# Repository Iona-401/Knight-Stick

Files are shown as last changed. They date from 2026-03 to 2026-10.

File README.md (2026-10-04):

# Knight-Stick 🕹️✈️

An open-source, fully 3D-printable flight stick engineered for high-precision simulation, modular assembly, and custom hardware integration.

---

## Overview

Commercial flight simulation gear is often prohibitively expensive or locked into closed ecosystems. **Knight-Stick** bridges that gap by providing a fully customizable, high-performance flight controller that you can manufacture at home using 3D printing and custom electronics.

Designed with a heavy focus on ergonomic feel, mechanical durability, and low-latency input processing, this project brings together mechanical CAD, PCB design, and embedded firmware.

---

## Key Features

* **Ergonomic & Modular CAD:** Designed for additive manufacturing, optimizing print orientation for strength and tactile comfort.
* **Precision Inputs:** Built around low-latency sensor architecture to ensure smooth, dead-zone-free axis tracking and crisp button actuation.
* **Custom Electronics:** Dedicated PCB layout for clean signal routing and reliable peripheral connections.
* **Open Source:** Complete hardware schematics, firmware source code, and STL/CAD files available for modification and community contribution.

---

## Repository Structure

```text
Knight-Stick/
├── cad/          # 3D printable models, mechanical assemblies, and STEP/STL files
├── hardware/     # Schematics, board layouts, and manufacturing files
├── firmware/     # Microcontroller source code and USB HID implementation
└── docs/         # Build guides, wiring diagrams, and assembly instructions

```

---

## Getting Started & Bill of Materials (BOM)

To build your own Knight-Stick, check out the documentation and release files in the respective directories:

1. **Hardware & Electronics:** Review the `hardware/` folder for schematic diagrams and PCB fabrication files.
2. **Mechanical Parts:** Grab the latest printable parts from the `cad/` folder. Ensure you follow recommended print settings for structural rigidity (e.g., adequate infill and wall counts).
3. **Firmware:** Flash the controller using the source code provided in the `firmware/` directory.

---

## Contributing

Contributions, feedback, and forks are always welcome! If you have ideas for improved gimbal geometry, alternative sensor integrations, or firmware enhancements, feel free to open an issue or submit a pull request.

---

## License

This project is open-source. See the repository for license details.

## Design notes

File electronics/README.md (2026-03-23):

# Electronics

This directory contains the complete electronics design for the **Knight Stick**
flight stick, including the schematic, PCB layout, and manufacturing outputs.

The electronics are built around an **ESP32**, providing USB and/or wireless
capabilities suitable for use as a flight simulation controller or general
HID device.

## Contents

- `kicad/`  
  Source design files created with **KiCad**, including:
  - Schematics
  - PCB layout
  - Project configuration files  
  These files represent the authoritative source for the electronics design.

- `gerbers/`  
  Fabrication-ready Gerber and drill files, organized by hardware revision.
  These files can be used directly with PCB manufacturers.

- `bom/`  
  Bill of Materials (BOM) files listing all electronic components required to
  assemble the PCB.

## Manufacturing Notes

- Gerber files are provided for convenience; always refer to the KiCad source
  files if modifications are required.
- Check the BOM and schematic carefully before ordering or assembling boards.

## License

All electronics design files in this directory are licensed under the  
**CERN Open Hardware License v2 – Strongly Reciprocal (CERN-OHL-S)**.

See the root `LICENSE-hardware.txt` file for full license terms.

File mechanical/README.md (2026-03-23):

# Mechanical Design

This directory contains the mechanical design files for the **Knight Stick**
flight stick. All mechanical components are designed to be **3D printable** and
are intended to integrate with the custom electronics.

The mechanical design was created in **Onshape** and exported for distribution
and fabrication.

## Contents

- 3D model exports (e.g., STEP and STL files) for individual parts and assemblies
- Mechanical drawings and documentation (where applicable)
- Visual assets such as renders or reference images

## 3D Printing Notes

- Parts are intended for consumer-grade FDM 3D printers.
- Recommended print settings (material, layer height, infill, orientation)
  should be documented here as the project matures.
- Verify tolerances before final assembly, especially for moving parts.

## 3D print List

### Grip
- Grip - Head.step :                  x1
- Grip - Left.step :                  x1
- Grip - Right.step :                 x1
- Grip - Trigger.step :               x1
- Grip - Paddle.step :                x1
- Grip - JoyStick Hat.step :          x1
- Grip - Dimple Hat.step :            x2
- Grip - Dome Hat.step :              x1
- Grip - Tact Button Cover.step :     x1
- Grip - Face Button Hat.step :       x1
- Grip - Head Button Hat.step :       x1
- Grip - Base Button Hat.step :       x1
- Grip - Face Plate.step :            x1

### X Axis
- X Axis - Grip Roller Cover.step :   x2
- X Axis - Grip Connector.step :      x1
- X Axis - Bearing Plate.step :       x2
- X Axis - Axis Damper.step :         x2
- X Axis - Roller Cover.step :        x2
- X Axis - Roller Plate.step :        x2

### Y Axis
- Y Axis - Bearing Plate.step :       x2
- Y Xxis - Axis Damper.step :         x2
- Y Axis - Side Plate.step :          x2

### Essentials
- Cams.step :                         x4
- FS - Sensor Holder.step :           x2
- FS-Base.step :                      x1
- FS-Box.step :                       x1

### Pre Made Print Profile
Full FS Print Profile.3mf : Load the File into Orca Slicer and it should load my print settings and the correct number of parts

## Source CAD

The authoritative mechanical design is maintained in Onshape.
Exported files in this directory represent fixed versions of the design at the
time of release.

Complete Model can be accessed at: https://cad.onshape.com/documents/ea7ebc91642e5ab2bd650249/w/252ca4d46198baf62f9cc347/e/4112f2ff40760dfaba3afdd9 

## License

All mechanical design files in this directory are licensed under the  
**CERN Open Hardware License v2 – Strongly Reciprocal (CERN-OHL-S)**.

See the root `LICENSE-hardware.txt` file for full license terms.

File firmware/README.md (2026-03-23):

# Firmware

ESP32 firmware for the 3D-printable flight stick.

VERY MUCH WORK IN PROGRESS

## License
All firmware and software source code in this directory
is licensed under the MIT License.

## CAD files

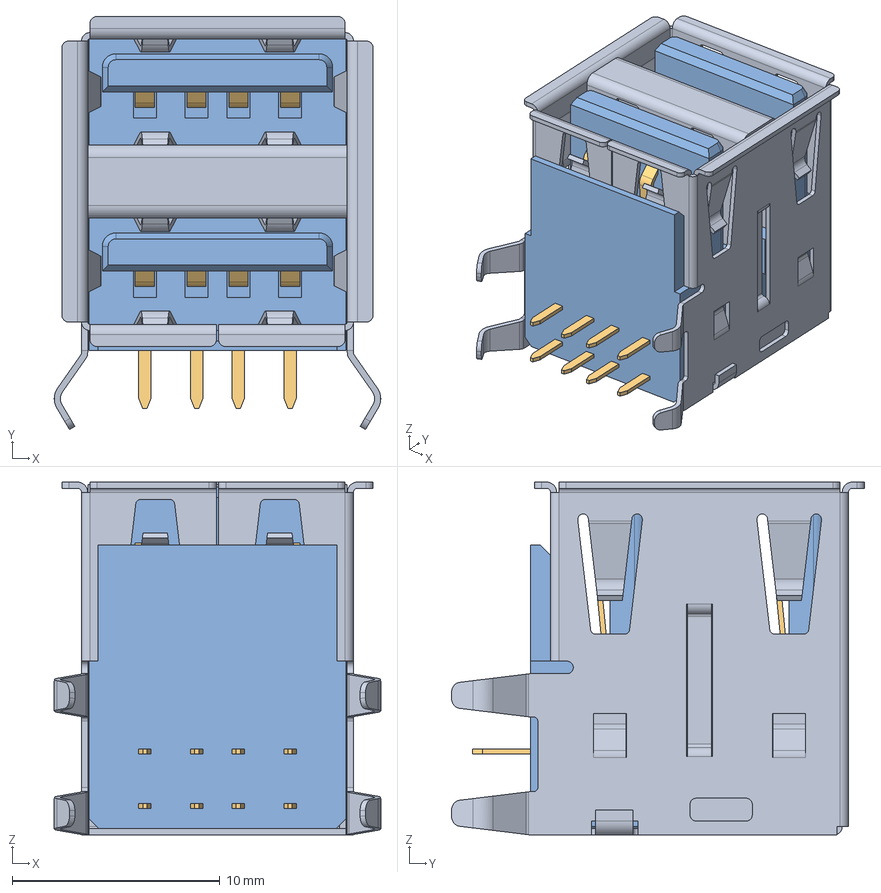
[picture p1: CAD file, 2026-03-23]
electronics/Kicad 3D Models/USB parts - GCT - USB1035-GF-P-0-B-B USB TYPE-A Stacked TH Right Angle.step
15.7 x 19.9 x 17.0 mm

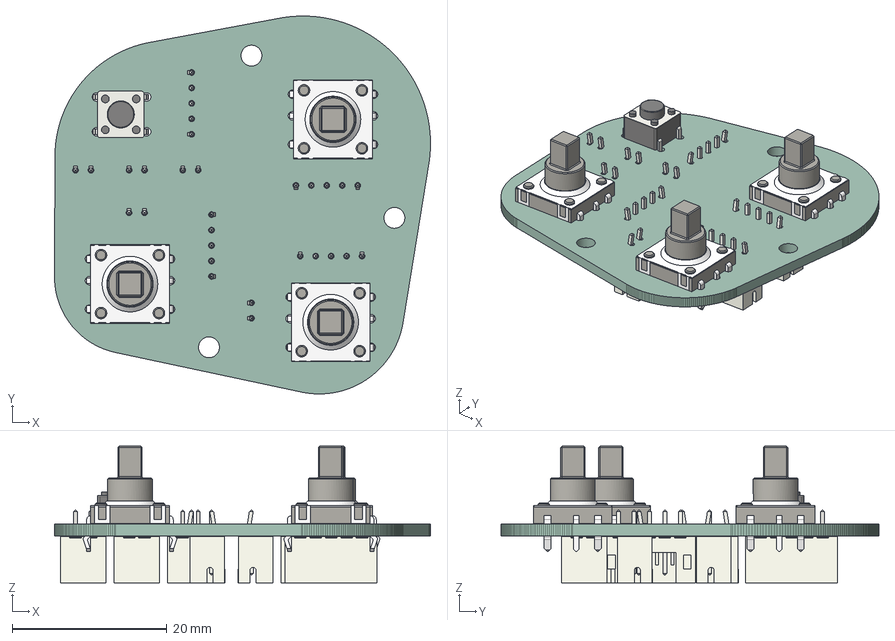
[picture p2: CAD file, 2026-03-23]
electronics/kicad/Faceboard/Faceboard.step
48.7 x 48.9 x 17.7 mm
5Way Pins x 3
5Way Body x 3
5Way Cover x 3
SW_PUSH_6mm_H5mm
JST_PH_B5B-PH-K_1x05_P2.00mm_Vertical x 4
JST_PH_B2B-PH-K_1x02_P2.00mm_Vertical x 5
In-Grip_FacePlate_PCB

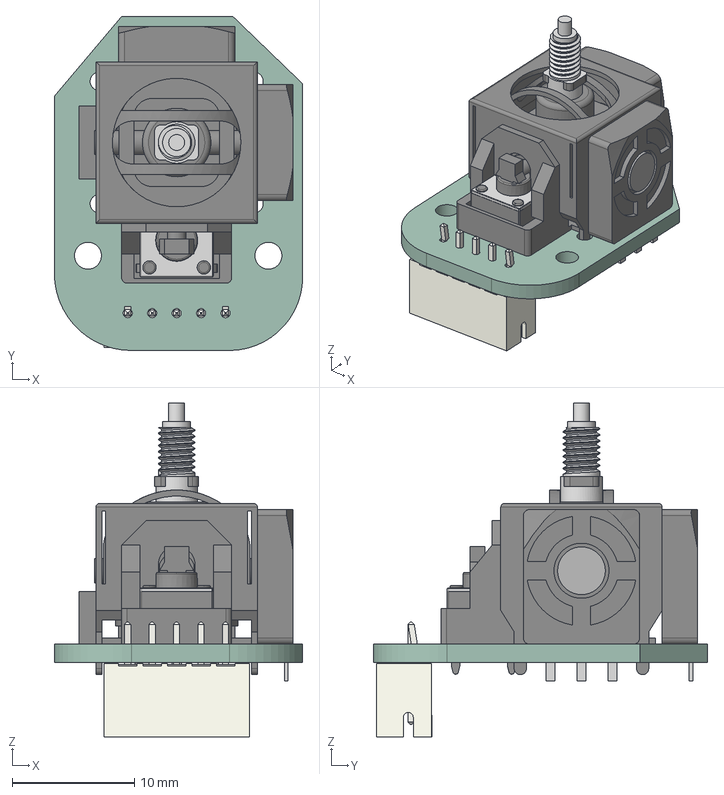
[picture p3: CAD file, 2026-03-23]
electronics/kicad/JoyStick Board/JoyStickBoard.step
20.3 x 27.3 x 27.3 mm
Hall Effect Joystick - Hall Effect Joystick
JST_PH_B5B-PH-K_1x05_P2.00mm_Vertical
JoyStickBoard_PCB

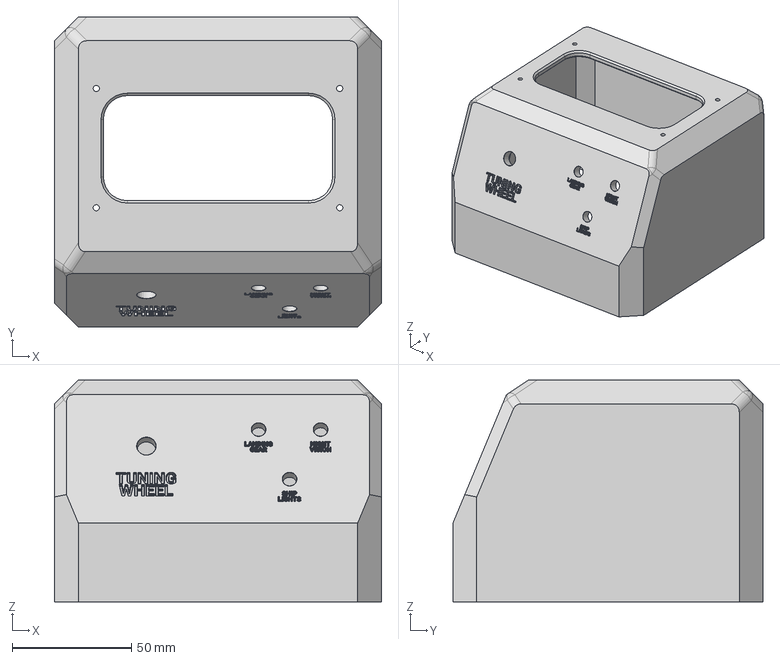
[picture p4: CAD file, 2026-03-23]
mechanical/Essentials/FS-Box.step
137.0 x 130.0 x 93.0 mm

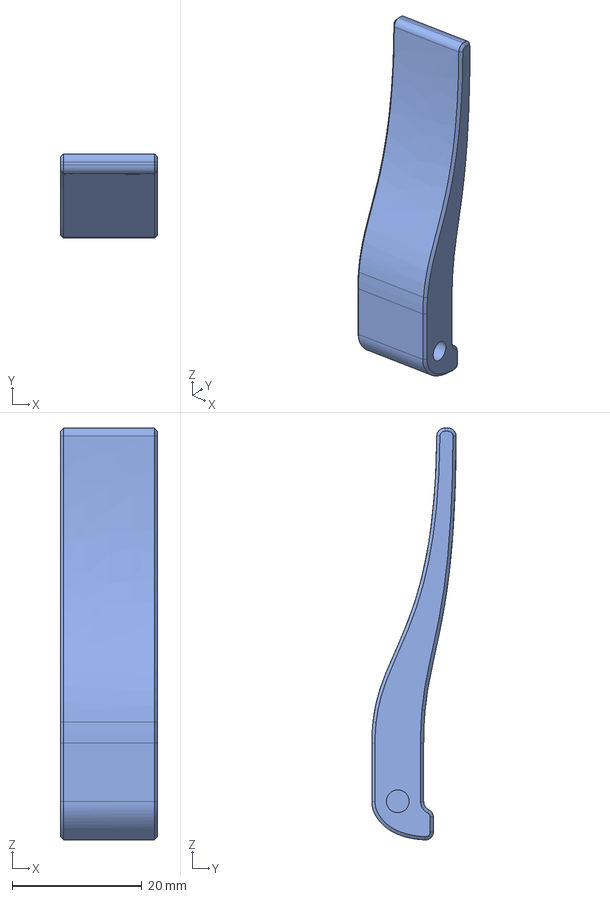
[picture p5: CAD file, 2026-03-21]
mechanical/Grip/Grip - Paddle.step
15.0 x 13.0 x 63.5 mm

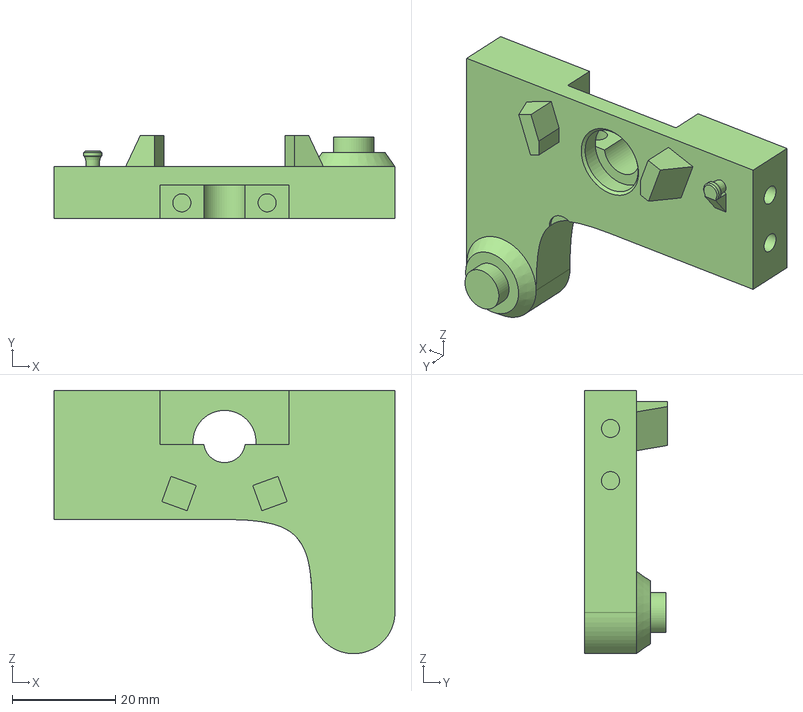
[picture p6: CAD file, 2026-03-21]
mechanical/X Axis/X Axis - Bearing Plate.step
66.0 x 16.0 x 51.0 mm

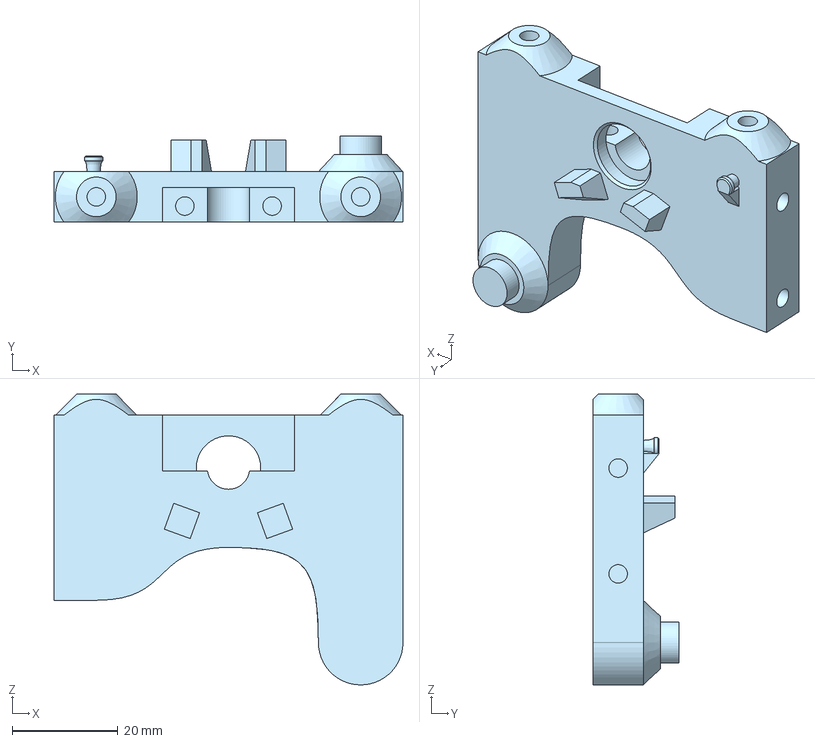
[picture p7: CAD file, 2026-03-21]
mechanical/Y Axis/Y Axis - Bearing Plate.step
66.0 x 16.2 x 55.0 mm

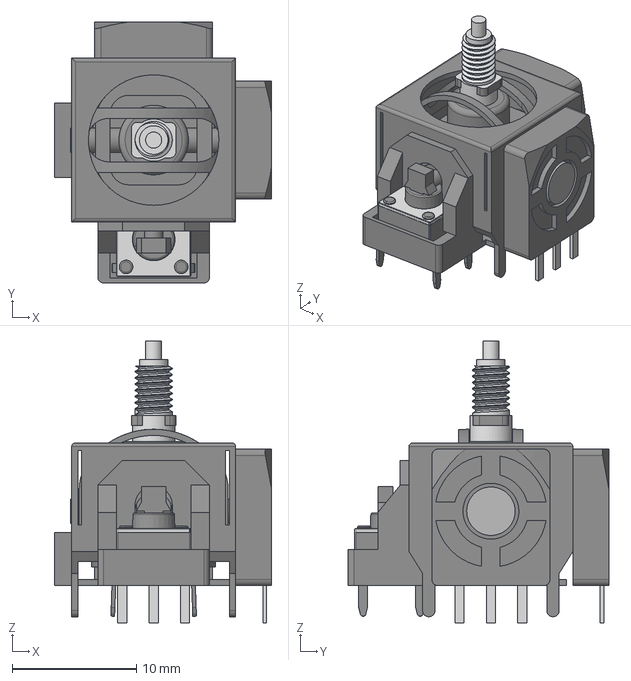
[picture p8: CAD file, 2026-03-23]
electronics/Kicad 3D Models/Hall Effect Joystick - Hall Effect Joystick.step
17.5 x 21.0 x 22.7 mm

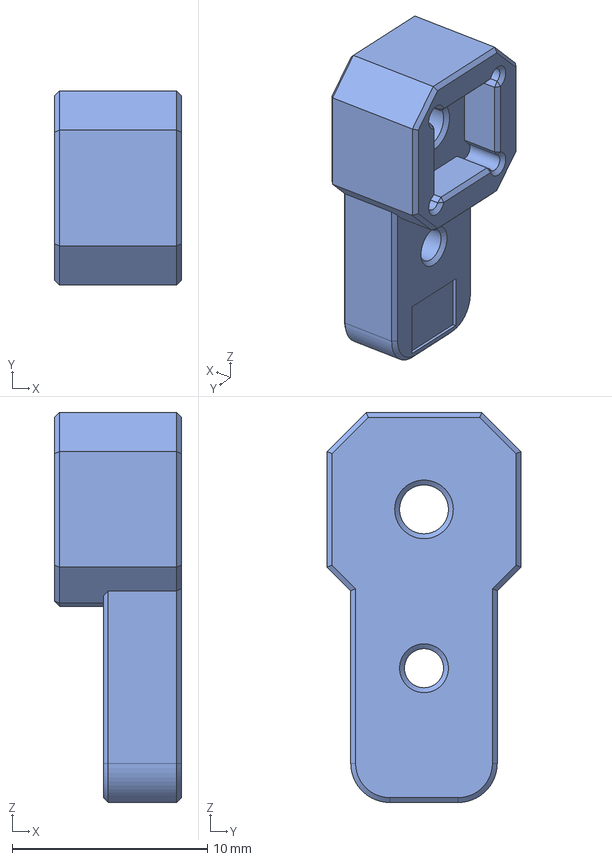
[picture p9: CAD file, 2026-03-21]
mechanical/Essentials/FS - Sensor Holder.step
6.50 x 9.92 x 20.0 mm

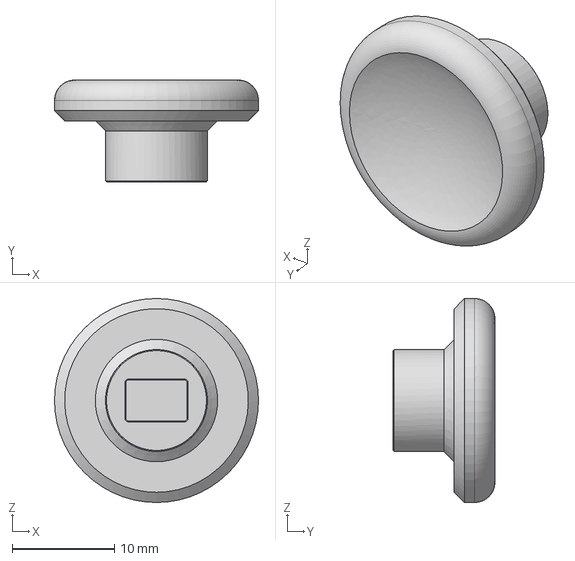
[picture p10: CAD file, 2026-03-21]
mechanical/Grip/Grip - JoyStick Hat.step
20.0 x 10.0 x 20.0 mm

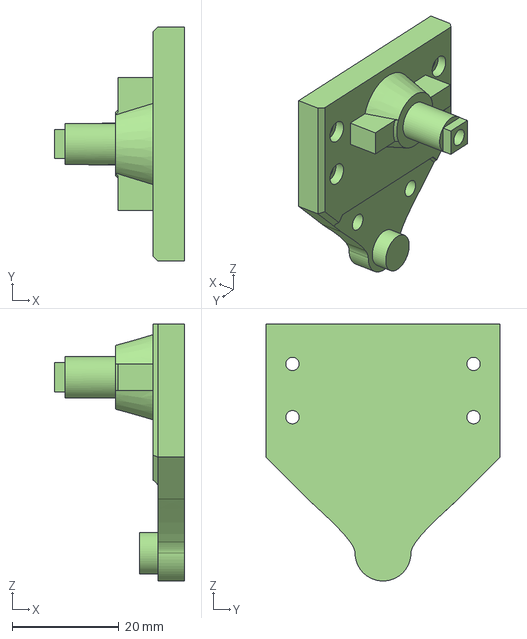
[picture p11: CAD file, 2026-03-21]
mechanical/X Axis/X Axis - Roller Plate.step
24.5 x 44.0 x 48.2 mm

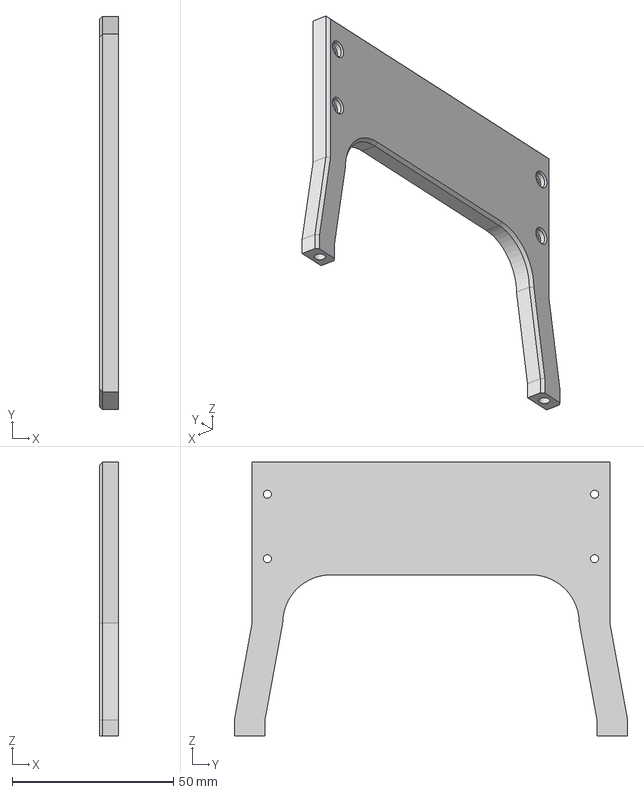
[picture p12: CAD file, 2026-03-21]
mechanical/Y Axis/Y Axis - Side Plate.step
6.00 x 122.0 x 85.0 mm

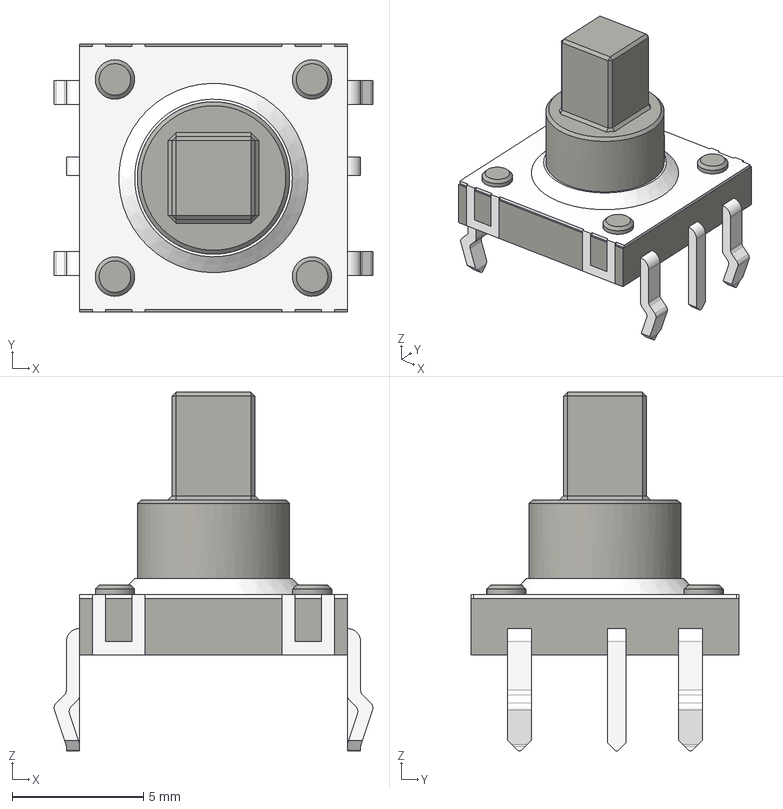
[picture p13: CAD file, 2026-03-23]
electronics/Kicad 3D Models/5-Way Button 10x10x10mm DIP-6.step
12.1 x 10.2 x 13.7 mm

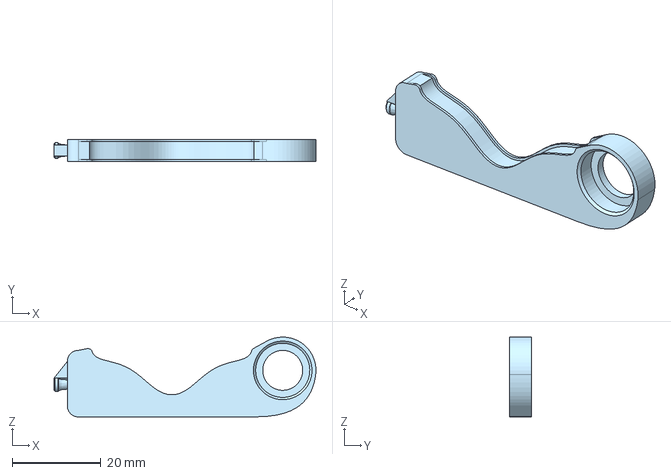
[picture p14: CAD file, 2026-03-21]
mechanical/Essentials/Cams.step
59.0 x 5.00 x 18.0 mm

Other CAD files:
mechanical/Grip/Grip - Right.step
mechanical/X Axis/X Axis - Axis Damper.step
mechanical/Y Axis/Y Xxis - Axis Damper.step
mechanical/Essentials/FS-Base.step
mechanical/Grip/Grip - Base Button Hat.step
mechanical/Grip/Grip - Dimple Hat.step
mechanical/Grip/Grip - Dome Hat.step
mechanical/Grip/Grip - Face Button Hat.step
mechanical/Grip/Grip - Face Plate.step
mechanical/Grip/Grip - Head Button Hat.step
mechanical/Grip/Grip - Head.step
mechanical/Grip/Grip - Left.step
mechanical/Grip/Grip - Tact Button Cover.step
mechanical/Grip/Grip - Trigger.step
mechanical/X Axis/X Axis - Grip Connector.step
mechanical/X Axis/X Axis - Grip Roller Cover.step
mechanical/X Axis/X Axis - Roller Cover.step

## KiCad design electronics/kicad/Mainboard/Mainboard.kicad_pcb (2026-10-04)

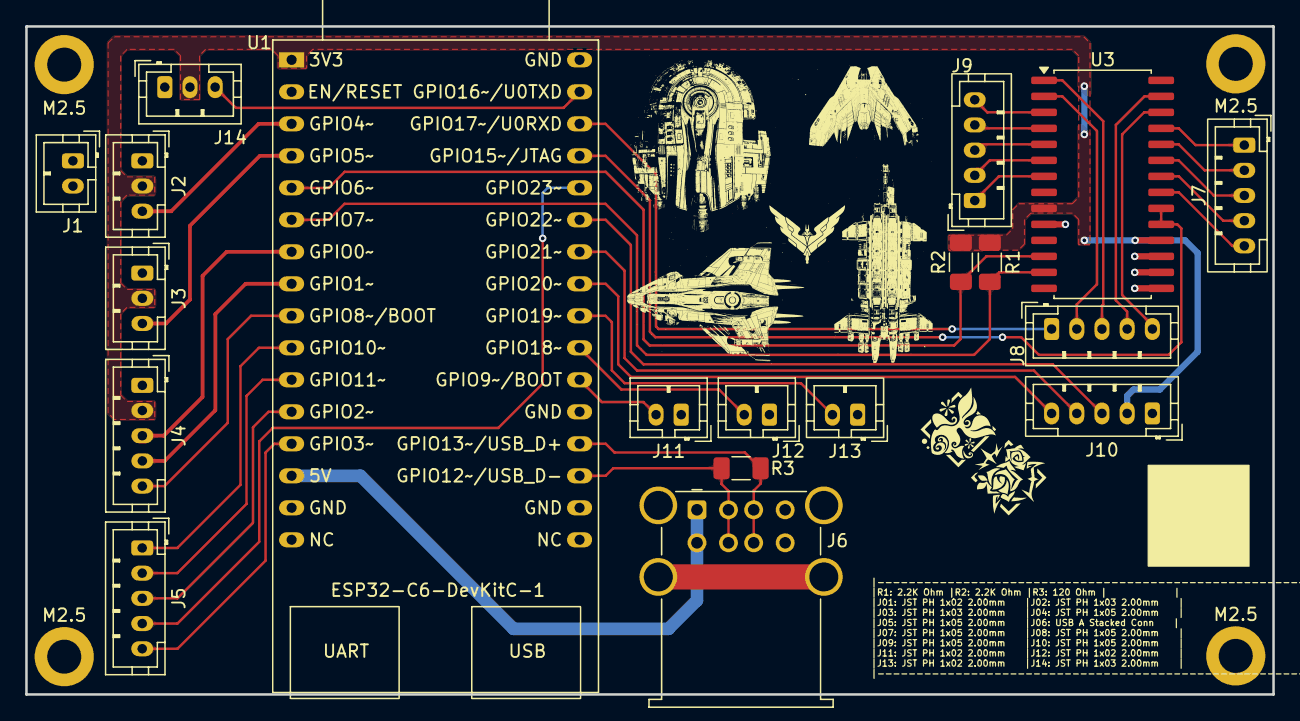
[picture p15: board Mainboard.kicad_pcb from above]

Board: 2 copper layers, 99.0 x 53.0 mm, 23 parts (0 on the bottom side), 40 nets.

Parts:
J1: GND Pair; JST_PH_B2B-PH-K_1x02_P2.00mm_Vertical
J2: X-Axis Hall; JST_PH_B3B-PH-K_1x03_P2.00mm_Vertical
J3: Y-Axis Hall; JST_PH_B3B-PH-K_1x03_P2.00mm_Vertical
J4, J5, J7, J8, J9, J10: Conn_01x05; JST_PH_B5B-PH-K_1x05_P2.00mm_Vertical
J6: USB_A_Stacked; USB_A_Wuerth_61400826021_Horizontal_Stacked
J11: Box Switch 1; JST_PH_B2B-PH-K_1x02_P2.00mm_Vertical
J12: Box Switch 2; JST_PH_B2B-PH-K_1x02_P2.00mm_Vertical
J13: Bos Switch 3; JST_PH_B2B-PH-K_1x02_P2.00mm_Vertical
J14: LED Strip; JST_PH_B3B-PH-K_1x03_P2.00mm_Vertical
M2.5, M2.5#2, M2.5#3, M2.5#4: MountingHole_2.7mm_M2.5_DIN965_Pad
R1, R2: 2K2; R_1206_3216Metric_Pad1.30x1.75mm_HandSolder
R3: 120; R_1206_3216Metric_Pad1.30x1.75mm_HandSolder
U1: ESP32-C6-DevKitC-1
U3: MCP23017x-x-SO; SOIC-28W_7.5x17.9mm_P1.27mm

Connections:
3V3: J2.2, J3.2, J4.2, J10.2, J14.2, R1.1, R2.1, U1.1 (3V3), U3.9 (V_{DD}), U3.18 (~RESET)
5V: J6.1 (VBUS1), J6.5 (VBUS2), U1.14 (5V)
Base Button: J5.1, U1.10 (GPIO10)
Box Switch 1: J11.2, U1.22 (GPIO9/BOOT)
Box Switch 2: J12.2, U1.23 (GPIO18)
Box Switch 3: J13.2, U1.24 (GPIO19)
CAN-HI: J6.3 (D1+), J6.7 (D2+), R3.1, U1.20 (GPIO13/USB_D+)
CAN-LOW: J6.2 (D1-), J6.6 (D2-), R3.2, U1.19 (GPIO12/USB_D-)
Extra: J14.3, U1.31 (GPIO16/U0TXD)
Face Button: J5.3, U1.12 (GPIO2)
Face Hat Left - Center: J7.5, U3.21 (GPA0)
Face Hat Left - Down: J7.3, U3.23 (GPA2)
Face Hat Left - Left: J7.4, U3.22 (GPA1)
Face Hat Left - Right: J7.2, U3.24 (GPA3)
Face Hat Left - Up: J7.1, U3.25 (GPA4)
Face Hat Right - Center: J8.3, U3.1 (GPB0)
Face Hat Right - Down: J8.1, U1.30 (GPIO17/U0RXD)
Face Hat Right - Left: J8.2, U3.2 (GPB1)
Face Hat Right - Right: J8.4, U3.27 (GPA6)
Face Hat Right - Up: J8.5, U3.26 (GPA5)
GND: J1.1, J1.2, J2.1, J3.1, J4.1, J6.4 (GND1), J6.8 (GND2), J10.1, J11.1, J12.1, J13.1, J14.1, M2.5.1, M2.5#2.1, M2.5#3.1, M2.5#4.1, U1.15 (GND), U1.18 (GND), U1.21 (GND), U1.32 (GND), U3.10 (V_{SS}), U3.15 (A0), U3.16 (A1), U3.17 (A2)
Head Button: J5.2, U1.11 (GPIO11)
INT: U1.29 (GPIO15/JTAG), U3.19 (INTB), U3.20 (INTA)
Joystick Button: J4.5, U1.9 (GPIO8/BOOT)
Joystick X: J4.3, U1.7 (GPIO0)
Joystick Y: J4.4, U1.8 (GPIO1)
Primary Trigger: J5.5, U1.13 (GPIO3)
RE A: J10.4, U1.26 (GPIO21)
RE B: J10.5, U1.25 (GPIO20)
RE Switch: J10.3, U1.27 (GPIO22)
SCK: R2.2, U1.5 (GPIO6), U3.12 (SCK)
SDA: R1.2, U1.6 (GPIO7), U3.13 (SDA)
Secondary Trigger: J5.4, U1.28 (GPIO23)
Thumb Hat - Center: J9.2, U3.6 (GPB5)
Thumb Hat - Down: J9.5, U3.3 (GPB2)
Thumb Hat - Left: J9.1, U3.7 (GPB6)
Thumb Hat - Right: J9.4, U3.4 (GPB3)
Thumb Hat - Up: J9.3, U3.5 (GPB4)
X-Axis: J2.3, U1.3 (GPIO4/MTMS)
Y-Axis: J3.3, U1.4 (GPIO5/MTDI)

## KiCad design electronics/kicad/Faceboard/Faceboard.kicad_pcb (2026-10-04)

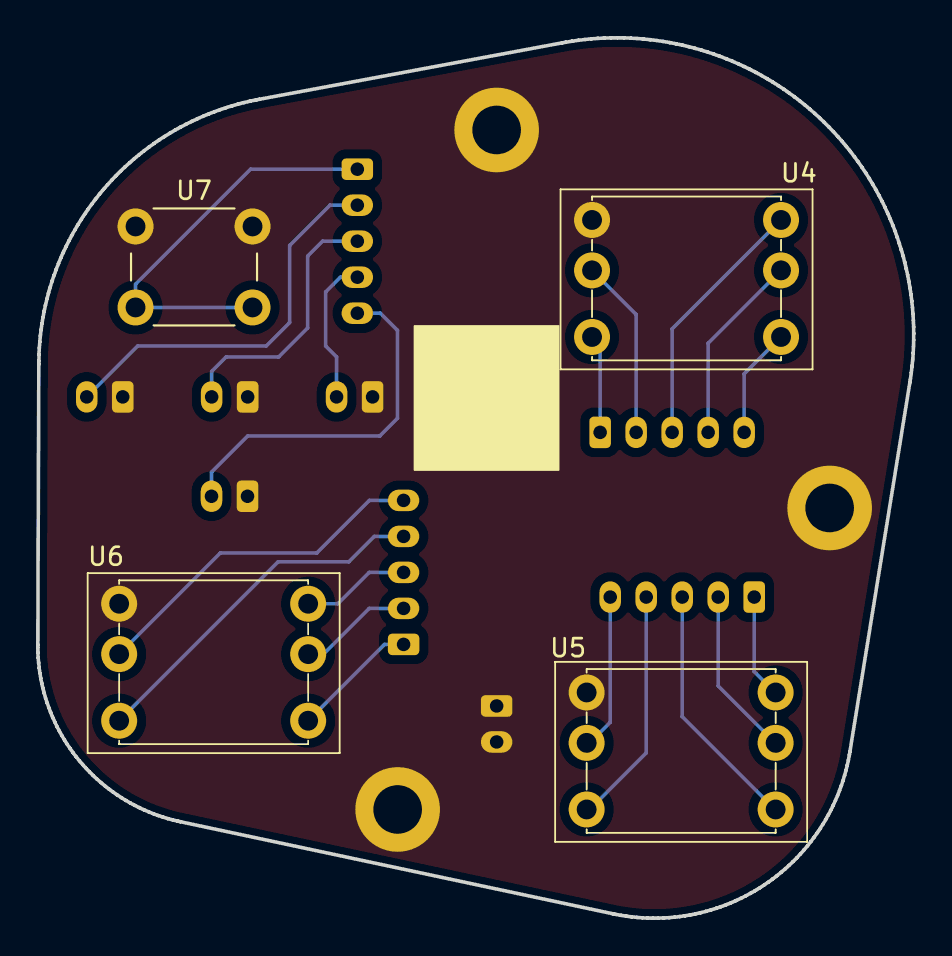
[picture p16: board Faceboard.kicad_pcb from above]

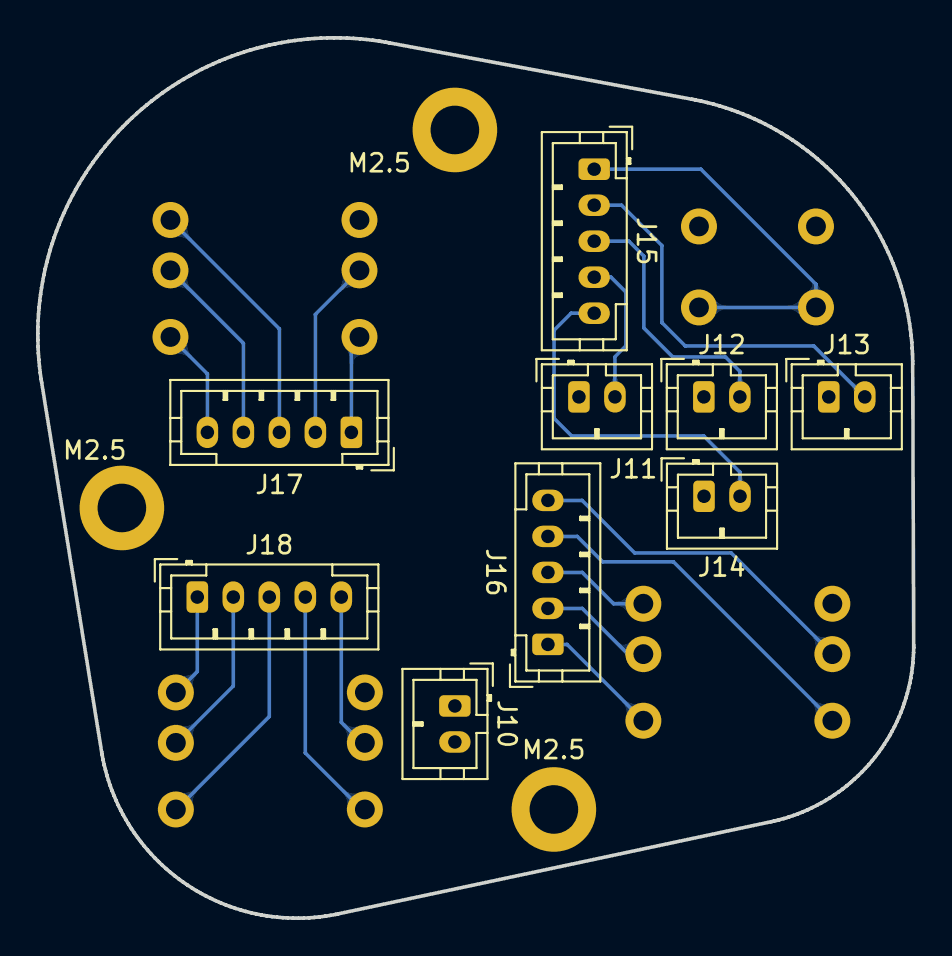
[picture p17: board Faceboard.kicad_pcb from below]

Board: 2 copper layers, 48.7 x 48.9 mm, 16 parts (12 on the bottom side), 21 nets.

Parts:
J10: Gnd; JST_PH_B2B-PH-K_1x02_P2.00mm_Vertical
J11: Primary Trigger 1; JST_PH_B2B-PH-K_1x02_P2.00mm_Vertical
J12: Secondary Trigger; JST_PH_B2B-PH-K_1x02_P2.00mm_Vertical
J13: Head Button; JST_PH_B2B-PH-K_1x02_P2.00mm_Vertical
J14: Base Button; JST_PH_B2B-PH-K_1x02_P2.00mm_Vertical
J15, J16, J17, J18: Conn_01x05; JST_PH_B5B-PH-K_1x05_P2.00mm_Vertical
M2.5, M2.5#2, M2.5#3: MountingHole_2.7mm_M2.5_DIN965_Pad
U4: Face Hat Top; 5-Way_Tact_Swt_6-pin
U5: Face Hat Right; 5-Way_Tactile_Swt_6-pin
U6: Face Hat Left; 5-Way_Tactile_Swt_6-pin
U7: Face Button; SW_PUSH_6mm_H5mm

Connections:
Base Button: J14.2, J15.5
Face Button: J15.1, U7.2
Face Hat Left - Center: J18.4, U6.3 (Center)
Face Hat Left - Down: J18.3, U6.6 (Down)
Face Hat Left - Left: J18.5, U6.2 (Left)
Face Hat Left - Right: J18.2, U6.5 (Right)
Face Hat Left - Up: J18.1, U6.4 (Up)
Face Hat Right - Center: J16.4, U5.3 (Center)
Face Hat Right - Down: J16.1, U5.6 (Down)
Face Hat Right - Left: J16.5, U5.2 (Left)
Face Hat Right - Right: J16.2, U5.5 (Right)
Face Hat Right - Up: J16.3, U5.4 (Up)
GND: J10.1, J10.2, J11.1, J12.1, J13.1, J14.1, M2.5.1, M2.5#2.1, M2.5#3.1, U4.1 (GND), U5.1 (GND), U6.1 (GND), U7.1
Head Button: J13.2, J15.2
Primary Trigger 1: J11.2, J15.4
Secondary Trigger: J12.2, J15.3
Thumb Hat - Center: J17.1, U4.3 (Center)
Thumb Hat - Down: J17.5, U4.6 (Down)
Thumb Hat - Left: J17.2, U4.2 (Left)
Thumb Hat - Right: J17.4, U4.5 (Right)
Thumb Hat - Up: J17.3, U4.4 (Up)

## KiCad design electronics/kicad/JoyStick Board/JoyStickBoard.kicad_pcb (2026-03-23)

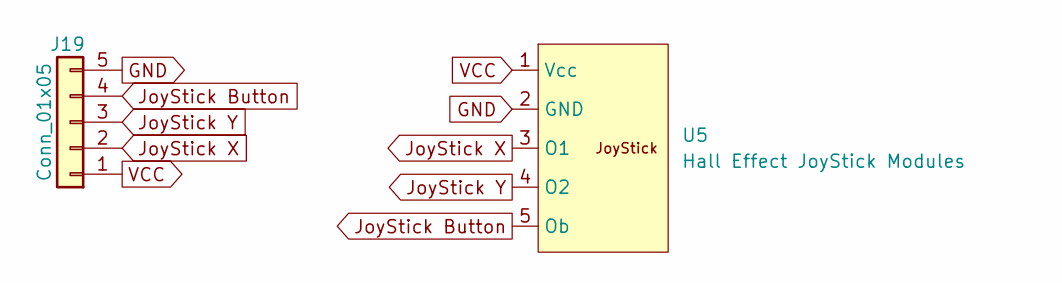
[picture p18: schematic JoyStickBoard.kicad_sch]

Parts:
J19: Conn_01x05; JST_PH_B5B-PH-K_1x05_P2.00mm_Vertical
U5: Hall Effect JoyStick Modules; Generic 2 axis Joystick with button

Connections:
GND: J19.5, U5.2 (GND)
JoyStick Button: J19.4, U5.5 (Ob)
JoyStick X: J19.2, U5.3 (O1)
JoyStick Y: J19.3, U5.4 (O2)
VCC: J19.1, U5.1 (Vcc)

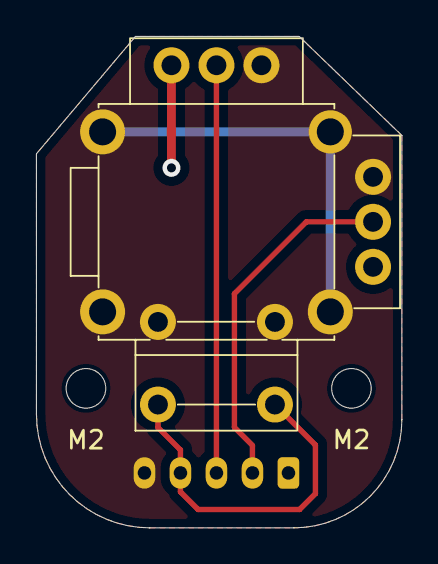
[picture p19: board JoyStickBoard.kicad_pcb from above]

Board: 2 copper layers, 20.3 x 27.3 mm, 4 parts (1 on the bottom side), 5 nets.

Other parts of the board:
M2, M2#2: MountingHole_2.2mm_M2_DIN965_Pad

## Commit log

2026-03-21 Added 3D Print README and STEP Files
    Added all the STEP Files for the Flight stick and modified the readme to reflect the print list.
    Added a base print profile for Orca Slicer.
    [Cams.step, FS - Sensor Holder.step, FS-Base.step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]
2026-03-23 Added all KiCad schematics. PCBs, projects files, and all related gerbers
    [5-Way Button 10x10x10mm DIP-6.step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]
2026-03-23 Update Full FS Print Profile.3mf
2026-03-23 Updates gerbers to include QR Code patch for JLCPCB
    [Faceboard-B_Cu.gbr, Faceboard-B_Mask.gbr, Faceboard-B_Paste.gbr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]
2026-03-23 Revise README for Knight Stick mechanical design
    Updated README to include detailed descriptions of mechanical design files and 3D printing notes.
2026-03-24 Updated Print Files to current version
2026-04-13 Updated PCB with New Silkscreen
    [Mainboard.kicad_pcb, Mainboard.kicad_sch]
2026-10-04 Updated Schematic
    Some Parts were replaced with Hand Solder SMD components where possible. Routing changed to work with new parts
    [Combined Board-B_Cu.gbr, Combined Board-B_Mask.gbr, Combined Board-B_Paste.gbr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]
